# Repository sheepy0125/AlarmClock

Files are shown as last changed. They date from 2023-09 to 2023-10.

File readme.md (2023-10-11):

# Alarm Clock

An Alarm Clock created as a school project.

## Hardware (general)

Uses an Arduino Uno (`atmega328p`) as the processor to control:
- 6x 7-segment digits for hours, minutes, and seconds
- 1x character LCD
- 1x snooze button (key switch)
- 1x rotary encoder to adjust time and change other settings (as seen on the LCD)
- 1x piezo buzzer
- 1x real time clock

### Shift registers

Because the Uno only has ~19 available pins, I used serial-in parallel-out buffered shift registers to send one bit at a time and release 8 bits all at once. Each shift register typically needs 2 pins at minimum (one for serial in and one for clock), however, for the seven segment displays I cut that down to 1 per and 1 total for an amortized 7 pins in total where all shift registers share one clock pulse.

## Software

All software is written in Rust with [Rahix's Arduino HAL crate](https://github.com/rahix/avr-hal).

## Design

TODO!!!

## Progress

- [x] Design schematic (done: 2023-09-17)
- [x] Order parts
- [ ] Breadboard / POC (in progress)
- [ ] Design PCB
- [ ] Order PCB parts
- [ ] Finish software (in progress)
- [x] Construct case
- [ ] Integration

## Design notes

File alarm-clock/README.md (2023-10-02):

alarm-clock
===========

Rust project for the _Arduino Uno_.

## Build Instructions
1. Install prerequisites as described in the [`avr-hal` README] (`avr-gcc`, `avr-libc`, `avrdude`, [`ravedude`]).

2. Run `cargo build` to build the firmware.

3. Run `cargo run` to flash the firmware to a connected board.  If `ravedude`
   fails to detect your board, check its documentation at
   <https://crates.io/crates/ravedude>.

4. `ravedude` will open a console session after flashing where you can interact
   with the UART console of your board.

[`avr-hal` README]: https://github.com/Rahix/avr-hal#readme
[`ravedude`]: https://crates.io/crates/ravedude

## License
Licensed under either of

 - Apache License, Version 2.0
   ([LICENSE-APACHE](LICENSE-APACHE) or <http://www.apache.org/licenses/LICENSE-2.0>)
 - MIT license
   ([LICENSE-MIT](LICENSE-MIT) or <http://opensource.org/licenses/MIT>)

at your option.

## Contribution
Unless you explicitly state otherwise, any contribution intentionally submitted
for inclusion in the work by you, as defined in the Apache-2.0 license, shall
be dual licensed as above, without any additional terms or conditions.

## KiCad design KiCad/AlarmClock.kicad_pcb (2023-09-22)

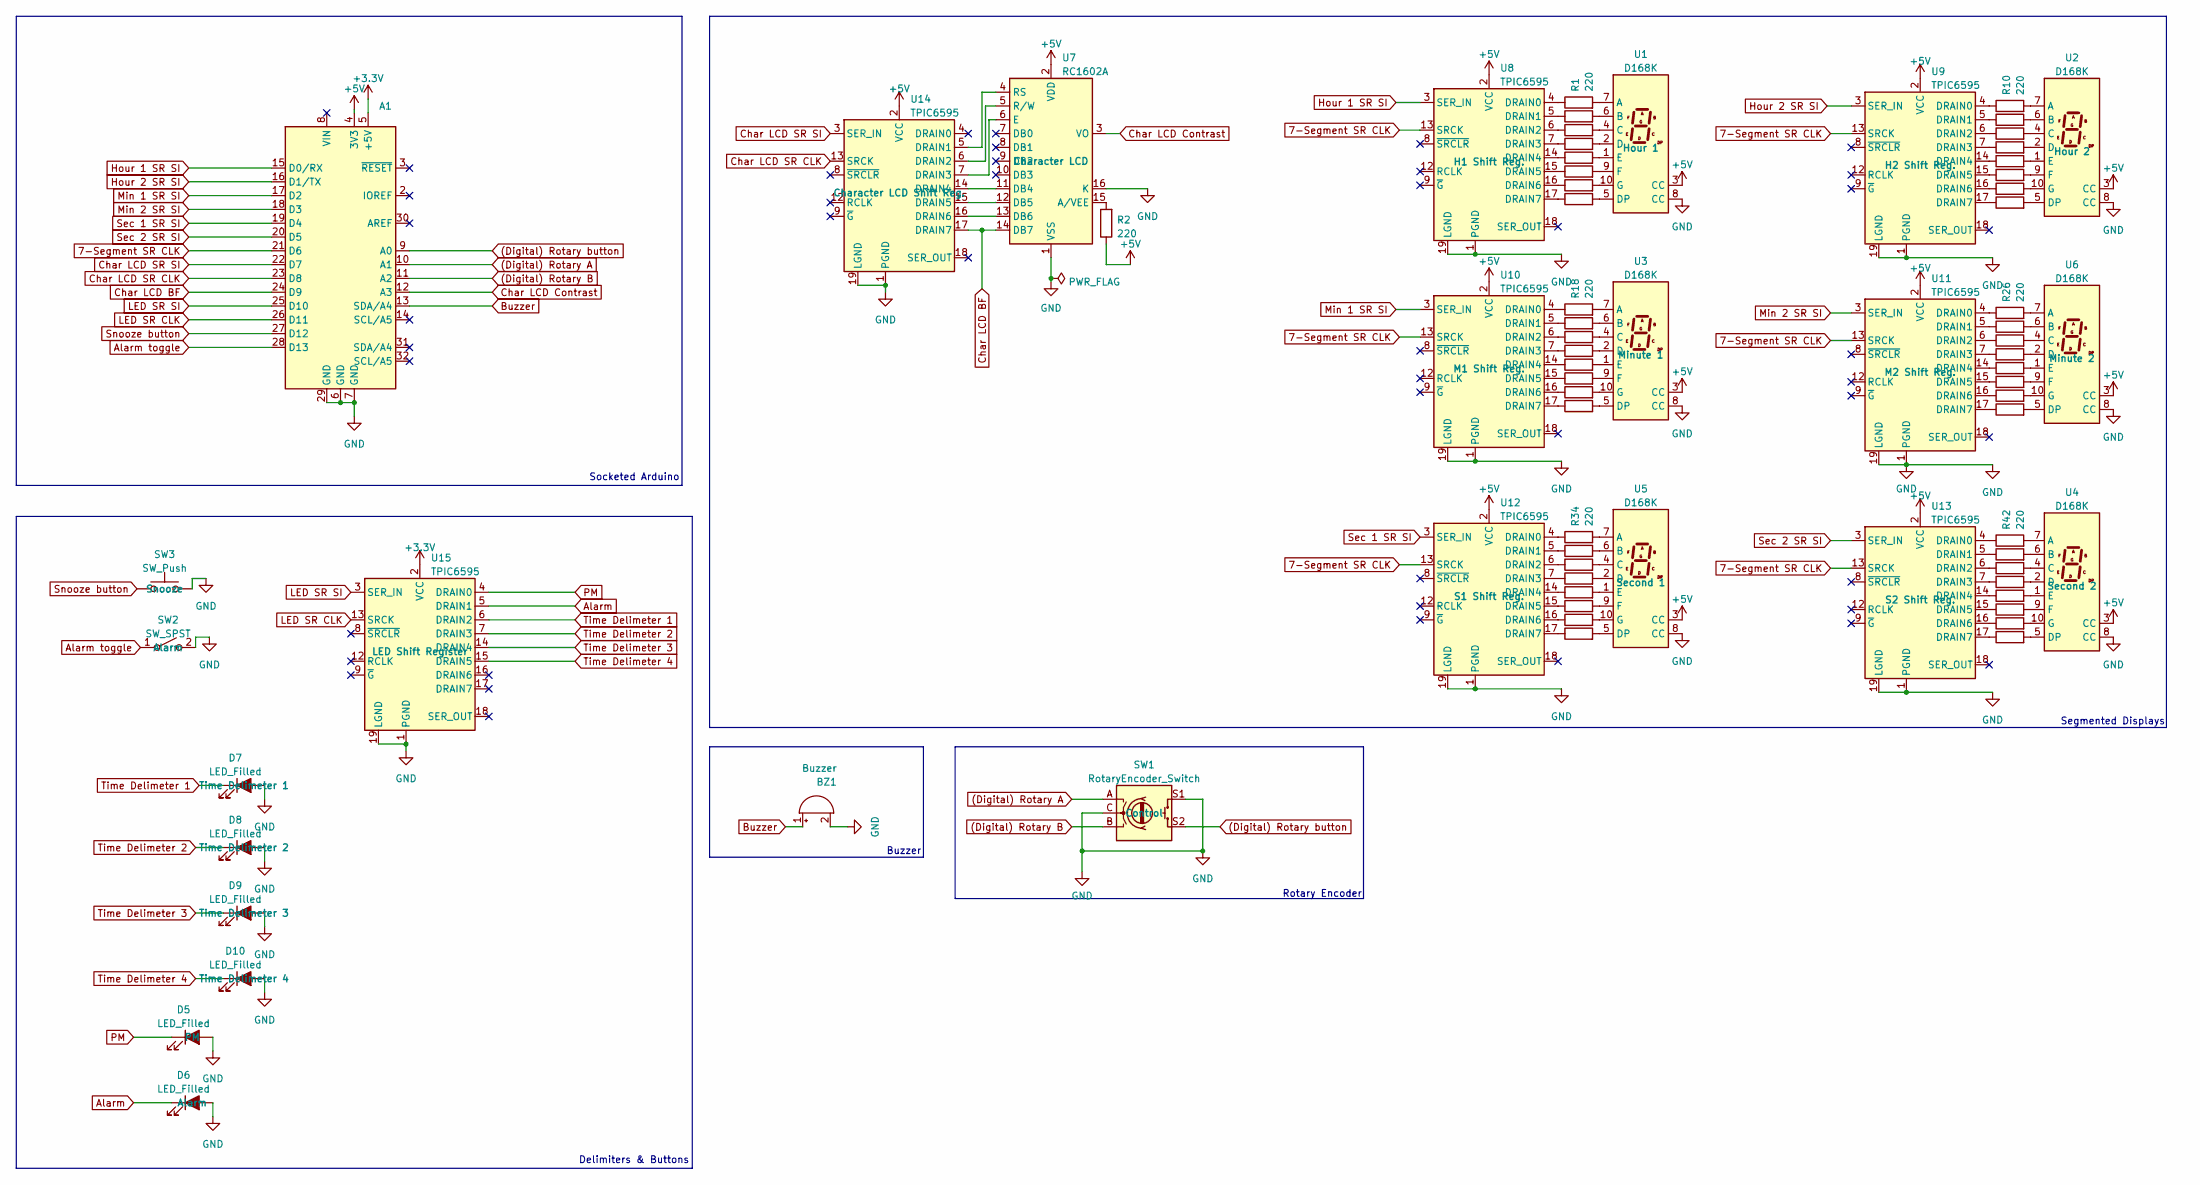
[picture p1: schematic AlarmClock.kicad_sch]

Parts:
A1: Arduino_UNO_R3; Arduino_UNO_R3_WithMountingHoles
BZ1: Buzzer; Buzzer_12x9.5RM7.6
D5, D6, D7, D8, D9, D10: LED_Filled; LED_D5.0mm
R1, R2, R3, R4, R5, R6, R7, R8, R9, R10, R11, R12, R13, R14, R15, R16, R17, R18, R19, R20, R21, R22, R23, R24, R25, R26, R27, R28, R29, R30, R31, R32, R33, R34, R35, R36, R37, R38, R39, R40, R41, R42, R43, R44, R45, R46, R47, R48, R49: 220; R_0402_1005Metric
SW1: RotaryEncoder_Switch; RotaryEncoder_Alps_EC11E-Switch_Vertical_H20mm
SW2: SW_SPST; SW_DIP_SPSTx01_Slide_6.7x4.1mm_W8.61mm_P2.54mm_LowProfile
SW3: SW_Push; SW_MX_1u
U1, U2, U3, U4, U5, U6: D168K; D1X8K
U7: RC1602A
U8, U9, U10, U11, U12, U13, U14, U15: TPIC6595; DIP-20_W7.62mm_Socket

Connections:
7-Segment SR CLK: A1.21 (D6), U8.13 (SRCK), U9.13 (SRCK), U10.13 (SRCK), U11.13 (SRCK), U12.13 (SRCK), U13.13 (SRCK)
(Digital) Rotary A: A1.10 (A1), SW1.A
(Digital) Rotary B: A1.11 (A2), SW1.B
(Digital) Rotary button: A1.9 (A0), SW1.S2
+3.3V: A1.5 (+5V), U15.2 (VCC)
Alarm: D6.1 (K), U15.5 (DRAIN1)
Alarm toggle: A1.28 (D13), SW2.1 (A)
Buzzer: A1.13 (SDA/A4), BZ1.1 (-)
Char LCD BF: A1.24 (D9), U7.14 (DB7), U14.17 (DRAIN7)
Char LCD Contrast: A1.12 (A3), U7.3 (VO)
Char LCD SR CLK: A1.23 (D8), U14.13 (SRCK)
Char LCD SR SI: A1.22 (D7), U14.3 (SER_IN)
GND: A1.6 (GND), A1.7 (GND), A1.29 (GND), BZ1.2 (+), D5.2 (A), D6.2 (A), D7.2 (A), D8.2 (A), D9.2 (A), D10.2 (A), SW1.C, SW1.S1, SW2.2 (B), SW3.2, U1.8 (CC), U2.8 (CC), U3.8 (CC), U4.8 (CC), U5.8 (CC), U6.8 (CC), U7.1 (VSS), U7.16 (K), U8.1 (PGND), U8.10 (PGND), U8.11 (PGND), U8.19 (LGND), U8.20 (PGND), U9.1 (PGND), U9.10 (PGND), U9.11 (PGND), U9.19 (LGND), U9.20 (PGND), U10.1 (PGND), U10.10 (PGND), U10.11 (PGND), U10.19 (LGND), U10.20 (PGND), U11.1 (PGND), U11.10 (PGND), U11.11 (PGND), U11.19 (LGND), U11.20 (PGND), U12.1 (PGND), U12.10 (PGND), U12.11 (PGND), U12.19 (LGND), U12.20 (PGND), U13.1 (PGND), U13.10 (PGND), U13.11 (PGND), U13.19 (LGND), U13.20 (PGND), U14.1 (PGND), U14.10 (PGND), U14.11 (PGND), U14.19 (LGND), U14.20 (PGND), U15.1 (PGND), U15.10 (PGND), U15.11 (PGND), U15.19 (LGND), U15.20 (PGND)
Hour 1 SR SI: A1.15 (D0/RX), U8.3 (SER_IN)
Hour 2 SR SI: A1.16 (D1/TX), U9.3 (SER_IN)
LED SR CLK: A1.26 (D11), U15.13 (SRCK)
Min 1 SR SI: A1.17 (D2), U10.3 (SER_IN)
Min 2 SR SI: A1.18 (D3), U11.3 (SER_IN)
unnamed: R1.2, U1.7 (A)
unnamed: R3.2, U1.6 (B)
unnamed: R4.2, U1.4 (C)
unnamed: R5.2, U1.2 (D)
unnamed: R9.2, U1.5 (DP)
unnamed: R6.2, U1.1 (E)
unnamed: R7.2, U1.9 (F)
unnamed: R8.2, U1.10 (G)
unnamed: R10.2, U2.7 (A)
unnamed: R11.2, U2.6 (B)
unnamed: R12.2, U2.4 (C)
unnamed: R13.2, U2.2 (D)
unnamed: R17.2, U2.5 (DP)
unnamed: R14.2, U2.1 (E)
unnamed: R15.2, U2.9 (F)
unnamed: R16.2, U2.10 (G)
unnamed: R18.2, U3.7 (A)
unnamed: R19.2, U3.6 (B)
unnamed: R20.2, U3.4 (C)
unnamed: R21.2, U3.2 (D)
unnamed: R25.2, U3.5 (DP)
unnamed: R22.2, U3.1 (E)
unnamed: R23.2, U3.9 (F)
unnamed: R24.2, U3.10 (G)
unnamed: R42.2, U4.7 (A)
unnamed: R43.2, U4.6 (B)
unnamed: R44.2, U4.4 (C)
unnamed: R45.2, U4.2 (D)
unnamed: R49.2, U4.5 (DP)
unnamed: R46.2, U4.1 (E)
unnamed: R47.2, U4.9 (F)
unnamed: R48.2, U4.10 (G)
unnamed: R34.2, U5.7 (A)
unnamed: R35.2, U5.6 (B)
unnamed: R36.2, U5.4 (C)
unnamed: R37.2, U5.2 (D)
unnamed: R41.2, U5.5 (DP)
unnamed: R38.2, U5.1 (E)
unnamed: R39.2, U5.9 (F)
unnamed: R40.2, U5.10 (G)
unnamed: R26.2, U6.7 (A)
unnamed: R27.2, U6.6 (B)
unnamed: R28.2, U6.4 (C)
unnamed: R29.2, U6.2 (D)
unnamed: R33.2, U6.5 (DP)
unnamed: R30.2, U6.1 (E)
unnamed: R31.2, U6.9 (F)
unnamed: R32.2, U6.10 (G)
unnamed: R1.1, U8.4 (DRAIN0)
unnamed: R3.1, U8.5 (DRAIN1)
unnamed: R4.1, U8.6 (DRAIN2)
unnamed: R5.1, U8.7 (DRAIN3)
unnamed: R6.1, U8.14 (DRAIN4)
unnamed: R7.1, U8.15 (DRAIN5)
unnamed: R8.1, U8.16 (DRAIN6)
unnamed: R9.1, U8.17 (DRAIN7)
unnamed: R10.1, U9.4 (DRAIN0)
unnamed: R11.1, U9.5 (DRAIN1)
unnamed: R12.1, U9.6 (DRAIN2)
unnamed: R13.1, U9.7 (DRAIN3)
unnamed: R14.1, U9.14 (DRAIN4)
unnamed: R15.1, U9.15 (DRAIN5)
unnamed: R16.1, U9.16 (DRAIN6)
unnamed: R17.1, U9.17 (DRAIN7)
unnamed: R18.1, U10.4 (DRAIN0)
unnamed: R19.1, U10.5 (DRAIN1)
unnamed: R20.1, U10.6 (DRAIN2)
unnamed: R21.1, U10.7 (DRAIN3)
unnamed: R22.1, U10.14 (DRAIN4)
unnamed: R23.1, U10.15 (DRAIN5)
unnamed: R24.1, U10.16 (DRAIN6)
unnamed: R25.1, U10.17 (DRAIN7)
unnamed: R26.1, U11.4 (DRAIN0)
unnamed: R27.1, U11.5 (DRAIN1)
unnamed: R28.1, U11.6 (DRAIN2)
unnamed: R29.1, U11.7 (DRAIN3)
unnamed: R30.1, U11.14 (DRAIN4)
unnamed: R31.1, U11.15 (DRAIN5)
unnamed: R32.1, U11.16 (DRAIN6)
unnamed: R33.1, U11.17 (DRAIN7)
unnamed: R34.1, U12.4 (DRAIN0)
unnamed: R35.1, U12.5 (DRAIN1)
unnamed: R36.1, U12.6 (DRAIN2)
unnamed: R37.1, U12.7 (DRAIN3)
unnamed: R38.1, U12.14 (DRAIN4)
unnamed: R39.1, U12.15 (DRAIN5)
unnamed: R40.1, U12.16 (DRAIN6)
unnamed: R41.1, U12.17 (DRAIN7)
unnamed: R42.1, U13.4 (DRAIN0)
unnamed: R43.1, U13.5 (DRAIN1)
unnamed: R44.1, U13.6 (DRAIN2)
unnamed: R45.1, U13.7 (DRAIN3)
unnamed: R46.1, U13.14 (DRAIN4)
unnamed: R47.1, U13.15 (DRAIN5)
unnamed: R48.1, U13.16 (DRAIN6)
unnamed: R49.1, U13.17 (DRAIN7)
unnamed: U7.4 (RS), U14.5 (DRAIN1)
unnamed: U7.5 (R/W), U14.6 (DRAIN2)
unnamed: U7.6 (E), U14.7 (DRAIN3)
unnamed: U7.11 (DB4), U14.14 (DRAIN4)
unnamed: U7.12 (DB5), U14.15 (DRAIN5)
unnamed: U7.13 (DB6), U14.16 (DRAIN6)
PM: D5.1 (K), U15.4 (DRAIN0)
Sec 1 SR SI: A1.19 (D4), U12.3 (SER_IN)
Sec 2 SR SI: A1.20 (D5), U13.3 (SER_IN)
Time Delimeter 1: D7.1 (K), U15.6 (DRAIN2)
Time Delimeter 2: D8.1 (K), U15.7 (DRAIN3)
Time Delimeter 3: D9.1 (K), U15.14 (DRAIN4)
Time Delimeter 4: D10.1 (K), U15.15 (DRAIN5)

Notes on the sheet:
Socketed Arduino
Buzzer
Segmented Displays
Rotary Encoder
Delimiters & Buttons

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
Board: 2 copper layers, 75 parts (1 on the bottom side), 130 nets, no tracks yet.

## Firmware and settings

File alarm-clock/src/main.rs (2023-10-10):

#![no_std]
#![no_main]
#![feature(abi_avr_interrupt)]
#![allow(incomplete_features)]
#![feature(adt_const_params)]
#![feature(trait_alias)]
#![feature(stmt_expr_attributes)]

use ag_lcd::{Blink, Cursor, Display as LcdDisplayMode, LcdDisplay, Lines};
use arduino_hal::{default_serial, delay_ms, delay_us, prelude::_void_ResultVoidExt, Delay, I2c};
use avr_device::{atmega328p::exint::pcicr::PCICR_SPEC, generic::Reg, interrupt};
use console::{println, set_console};
use core::{cell::RefCell, fmt::Write, marker::PhantomData};
use embedded_hal::digital::v2::OutputPin;
use heapless::String;
use pins::{RotaryEncoderPins, ShiftRegisterPins};
use rotary_encoder::RotaryEncoder;
use rtc::RTC;
use shared::{Time, TimeDigits, UsbSerial};
use shift_register::ShiftRegister;
use shift_register_driver::sipo::ShiftRegister8 as DecomposableShiftRegister;
use snooze_button::SnoozeButton;
use state::{DateSetState, Menu, OperationalMode, State, StateLogic, TimeSetState};
use time_display::{Display as TimeDisplayTrait, HoursMinutes, Seconds};
use ufmt::uwriteln;

use crate::{
    console::debug,
    interrupts::millis,
    shared::{MILLIS_OVERFLOW_UPDATE_MARGIN, UPDATE_DELTATIME},
    time_display::{DIGITS, HOUR_MINUTE_DISPLAY},
};

pub mod console;
pub mod interrupts;
pub mod panic;
pub mod pins;
mod rotary_encoder;
mod rtc;
pub mod shared;
pub mod shift_register;
mod snooze_button;
pub mod state;
mod time_display;

#[arduino_hal::entry]
fn main() -> ! {
    let peripherals = arduino_hal::Peripherals::take().unwrap();
    let pins = arduino_hal::pins!(peripherals);
    let mut serial: UsbSerial = default_serial!(peripherals, pins, shared::BAUD_RATE);
    set_console(serial);

    let mut state = State::new();

    println!("Hello from the Alarm Clock!");

    // Set up pin handles
    let hours_minute_display_shift_register_pins = ShiftRegisterPins {
        serial_input: pins.d2.into_output() as pins::hours_minutes_display::SerialIn,
        clock: pins.d3.into_output() as pins::hours_minutes_display::Clock,
        latch: pins.d4.into_output() as pins::hours_minutes_display::Latch,
    };
    let seconds_display_shift_register_pins = ShiftRegisterPins {
        serial_input: pins.d5.into_output() as pins::seconds_display::SerialIn,
        clock: pins.d6.into_output() as pins::seconds_display::Clock,
        latch: pins.d7.into_output() as pins::seconds_display::Latch,
    };
    let rotary_encoder_pins = RotaryEncoderPins {
        a: pins.d13.into_pull_up_input(),
        b: pins.a0.into_pull_up_input(),
        button: pins.d12.into_pull_up_input(),
    };
    let character_lcd_shift_register_pins = ShiftRegisterPins {
        serial_input: pins.d8.into_output() as pins::character_lcd::SerialIn,
        clock: pins.d9.into_output() as pins::character_lcd::Clock,
        latch: pins.d10.into_output() as pins::character_lcd::Latch,
    };
    let snooze_button_pin = pins.d11.into_pull_up_input() as pins::snooze::Button;
    let mut buzzer_pin = {
        let mut pin = pins.a3.into_output() as pins::buzzer::Buzzer;
        pin.set_low();
        pin
    };
    let mut alarm_led_pin = pins.a1.into_output() as pins::leds::Alarm;
    let mut pm_led_pin = pins.a2.into_output() as pins::leds::PM;
    let mut iic_pins = pins::IICPins {
        sda: pins.a4.into_pull_up_input(),
        scl: pins.a5.into_pull_up_input(),
    };

    // Intialize interrupts
    interrupts::millis_init(peripherals.TC0);
    unsafe {
        interrupts::rotary_encoder_init(
            &peripherals.EXINT.pcicr,
            &peripherals.EXINT.pcmsk0,
            &rotary_encoder_pins.a,
            &rotary_encoder_pins.button,
        );
        interrupts::snooze_button_init(
            &peripherals.EXINT.pcicr,
            &peripherals.EXINT.pcmsk0,
            &snooze_button_pin,
        );
    };
    unsafe { avr_device::interrupt::enable() };

    // Time initialization
    debug!("[DEBUG] I2C & RTC initialization");
    let mut i2c = I2c::new(peripherals.TWI, iic_pins.sda, iic_pins.scl, 1);
    let mut rtc = RTC::new(i2c);

    // Display initialization
    debug!("[DEBUG] Hours & minutes display initialization");

    // Plop the hours minute display to the global so the interrupt handler can access it
    interrupt::free(|critical_section| {
        let hours_minutes_display = HoursMinutes::new(
            ShiftRegister::<16_usize, _, _, _>::from_pins(hours_minute_display_shift_register_pins),
        );
        HOUR_MINUTE_DISPLAY
            .borrow(critical_section)
            .replace(Some(hours_minutes_display));
    });
    debug!("[DEBUG] Seconds display initialization");
    let mut seconds_display = Seconds::new(ShiftRegister::<{ 2 * 8_usize }, _, _, _>::from_pins(
        seconds_display_shift_register_pins,
    ));
    debug!("[DEBUG] Character LCD shift register initialization");
    let mut character_lcd_shift_register = DecomposableShiftRegister::new(
        character_lcd_shift_register_pins.clock,
        character_lcd_shift_register_pins.latch,
        character_lcd_shift_register_pins.serial_input,
    );
    let mut character_lcd_pins = character_lcd_shift_register.decompose();
    let mut character_lcd: LcdDisplay<_, _> = match character_lcd_pins {
        // Refer to KiCad schematic for pin layout
        [_, rs, _, enabled, db4, db5, db6, db7] => {
            LcdDisplay::new(rs, enabled, arduino_hal::Delay::new())
                .with_half_bus(db4, db5, db6, db7)
                .with_display(LcdDisplayMode::On)
                .with_cursor(Cursor::Off)
                .with_lines(Lines::TwoLines)
                .build()
        }
    };

    // Controls initialization
    debug!("[DEBUG] Rotary encoder initialization");
    let mut rotary_encoder = RotaryEncoder::from_pins(rotary_encoder_pins);
    debug!("[DEBUG] Snooze button initialization");
    let mut snooze_button = SnoozeButton::new(snooze_button_pin);

    interrupt::free(|critical_section| {
        rtc.set_time(&state.time, &critical_section);
    });

    // Main loop
    loop {
        delay_ms(UPDATE_DELTATIME);
        debug!("[DEBUG] Loop iteration");

        // Update time
        if let Some(new_time) = rtc.read_time(&mut state.digits) {
            state.time = new_time;
        }
        interrupt::free(|critical_section| {
            DIGITS
                .borrow(critical_section)
                .replace(state.digits.clone());
        });

        character_lcd.clear();
        character_lcd.set_position(0, 0);
        delay_us(100_u32);
        character_lcd.print("alarmed clock");
        delay_us(100_u32);
        character_lcd.set_position(0, 1);
        delay_us(100_u32);
        let mut buf = [0_u8; 4];
        character_lcd.print(
            char::from_digit(state.digits.hours.0 as u32, 10_u32)
                .unwrap()
                .encode_utf8(&mut buf),
        );
        character_lcd.print(
            char::from_digit(state.digits.hours.1 as u32, 10_u32)
                .unwrap()
                .encode_utf8(&mut buf),
        );
        character_lcd.print(":");
        character_lcd.print(
            char::from_digit(state.digits.minutes.0 as u32, 10_u32)
                .unwrap()
                .encode_utf8(&mut buf),
        );
        character_lcd.print(
            char::from_digit(state.digits.minutes.1 as u32, 10_u32)
                .unwrap()
                .encode_utf8(&mut buf),
        );
        character_lcd.print(":");
        character_lcd.print(
            char::from_digit(state.digits.seconds.0 as u32, 10_u32)
                .unwrap()
                .encode_utf8(&mut buf),
        );
        character_lcd.print(
            char::from_digit(state.digits.seconds.1 as u32, 10_u32)
                .unwrap()
                .encode_utf8(&mut buf),
        );

        rotary_encoder.update();
        snooze_button.update();
        seconds_display.display(&state);
    }
}

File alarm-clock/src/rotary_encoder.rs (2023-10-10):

//! Rotary encoder for interfacing with the character LCD and setting aspects of
//! alarm clock; only the rotary encoder is implemented here!!
//! See the rotary encoder interrupt in `interrupts.rs` as that is where the encoder
//! state is set.

use crate::{
    console::{debug, println},
    interrupts::{changed_state, get_rotary_encoder_state, RotaryEncoderState},
    pins::{self, RotaryEncoderPins},
    shared::{
        PinState::{PinState, HIGH, LOW},
        TimeDigits,
    },
    shift_register::ShiftRegister,
};
use arduino_hal::{
    hal::port::{self, Dynamic},
    port::{
        mode::{Input, Output, PullUp},
        Pin,
    },
};
use avr_device::interrupt::CriticalSection;
use core::sync::atomic::AtomicBool;

pub struct RotaryEncoder {
    a: pins::rotary_encoder::A,
    b: pins::rotary_encoder::B,
    button: pins::rotary_encoder::Button,
    state: RotaryEncoderState,
    pub changed: bool,
}
impl RotaryEncoder {
    pub fn new(
        a: pins::rotary_encoder::A,
        b: pins::rotary_encoder::B,
        button: pins::rotary_encoder::Button,
    ) -> Self {
        Self {
            a,
            b,
            button,
            changed: false,
            state: RotaryEncoderState {
                a: false,
                b: false,
                button: false,
            },
        }
    }

    pub fn from_pins(rotary_encoder_pins: RotaryEncoderPins) -> Self {
        Self::new(
            rotary_encoder_pins.a,
            rotary_encoder_pins.b,
            rotary_encoder_pins.button,
        )
    }

    pub fn update(&mut self) {
        let state = get_rotary_encoder_state();
        // Only detect rotary encoder changes, ignore snooze press
        self.changed = changed_state()
            && (self.state.a != state.a
                || self.state.b != state.b
                || self.state.button != state.button);
        debug!(
            "[DEBUG] [ROT ENC] Rotary encoder update, changed: {}",
            match self.changed {
                true => "YES",
                false => "NO",
            }
        );
        self.state = state;
    }

    pub fn rotated_clockwise(&mut self) -> bool {
        let ret = self.changed && (self.state.a != self.state.b);
        self.changed = false;
        ret
    }

    pub fn button(&mut self) -> bool {
        let ret = self.changed && self.state.button;
        self.changed = false;
        ret
    }
}

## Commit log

2023-09-17 Start of PCB design
    [AlarmClock.kicad_pcb, AlarmClock.kicad_sch]
2023-09-18 reformat your questionable schematic, and import components into pcb editor
    [AlarmClock.kicad_pcb, AlarmClock.kicad_sch]
2023-09-18 fix a very small mistake
    [AlarmClock.kicad_sch]
2023-09-22 Update schematic to adhere to ERC
    [AlarmClock.kicad_pcb, AlarmClock.kicad_sch]
2023-10-02 Add interfaces for most peripherals and interrupts
